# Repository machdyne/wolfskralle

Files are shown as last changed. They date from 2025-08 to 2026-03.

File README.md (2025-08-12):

# Wolfskralle Programmer

Wolfskralle is an ISP + spring contact programmer for CH32 MCUs and [Zwölf](https://github.com/machdyne/zwolf) [LS10](https://machdyne.com/product/zwolf-ls10/) modules.

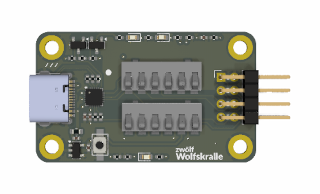
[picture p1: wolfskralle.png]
Wolfskralle


This repo will contain schematics, pinouts and a 3D-printable socket housing for the spring connector.

Find more information on the [Wolfskralle product page](https://machdyne.com/product/wolfskralle-programmer/).

## Pinout

```
7 5 3 1
8 6 4 2
```

| Pin | Signal |
| --- | --- |
| 1 | ZP1 (Zwölf GSCL) / SWCLK | 
| 3 | ZP2 (Zwölf GSDA) | 
| 5 | SWIO (programmer swio) | 
| 7 | RESET (programmer reset) | 
| 2 | TPWR3V3 (target power) | 
| 4 | TSWIO (target swio) | 
| 6 | TRESET (target reset) | 
| 8 | GND | 

## License

The contents of this repo are released under the [Lone Dynamics Open License](LICENSE.md).

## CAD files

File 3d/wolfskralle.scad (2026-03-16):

/*
 * Wolfskralle Socket Housing
 * Copyright (c) 2025 Lone Dynamics Corporation. All rights reserved.
 *
 * required hardware:
 *  - 4 x M3 x 16mm countersunk bolts
 *  - 4 x M3 nuts
 *
 */

$fn = 100;

height = 16 - 1.6 - 2;

mmx();

module mmx() {    
        
    translate([5,0,0]) cube([2,10,height], center=true);    
    
    difference() {
        
        union() {
        translate([-21,0,3.7]) cube([15,28,5], center=true);    
        cube([28,28,height], center=true);    
        }
        
        translate([10,0,-12.5+5.5]) cube([10,25/2,height], center=true);    
        
        translate([-4,0,0]) cube([10,25,15], center=true);    
        
        translate([0,0,-5]) cube([25,10,5], center=true);    
        
        translate([-5,16,-8]) cube([23,15,5], center=true);    
        translate([-5,-16,-8]) cube([23,15,5], center=true);    

        translate([-4.25,-0.5,3]) cube([16.5,14,20], center=true);
        
        //translate([-3,0,-10]) cube([19,19,20], center=true);

        translate([21/2, 12.5-3, -10]) cylinder(d=3.2, h=100);
        translate([21/2, -12.5+3, -10]) cylinder(d=3.2, h=100);
        
        translate([21/2-36, 12.5-3, -10]) cylinder(d=3.2, h=100);
        translate([21/2-36, -12.5+3, -10]) cylinder(d=3.2, h=100);
        
        cylinder(d=3.5, h=100);
        
    }
    
}

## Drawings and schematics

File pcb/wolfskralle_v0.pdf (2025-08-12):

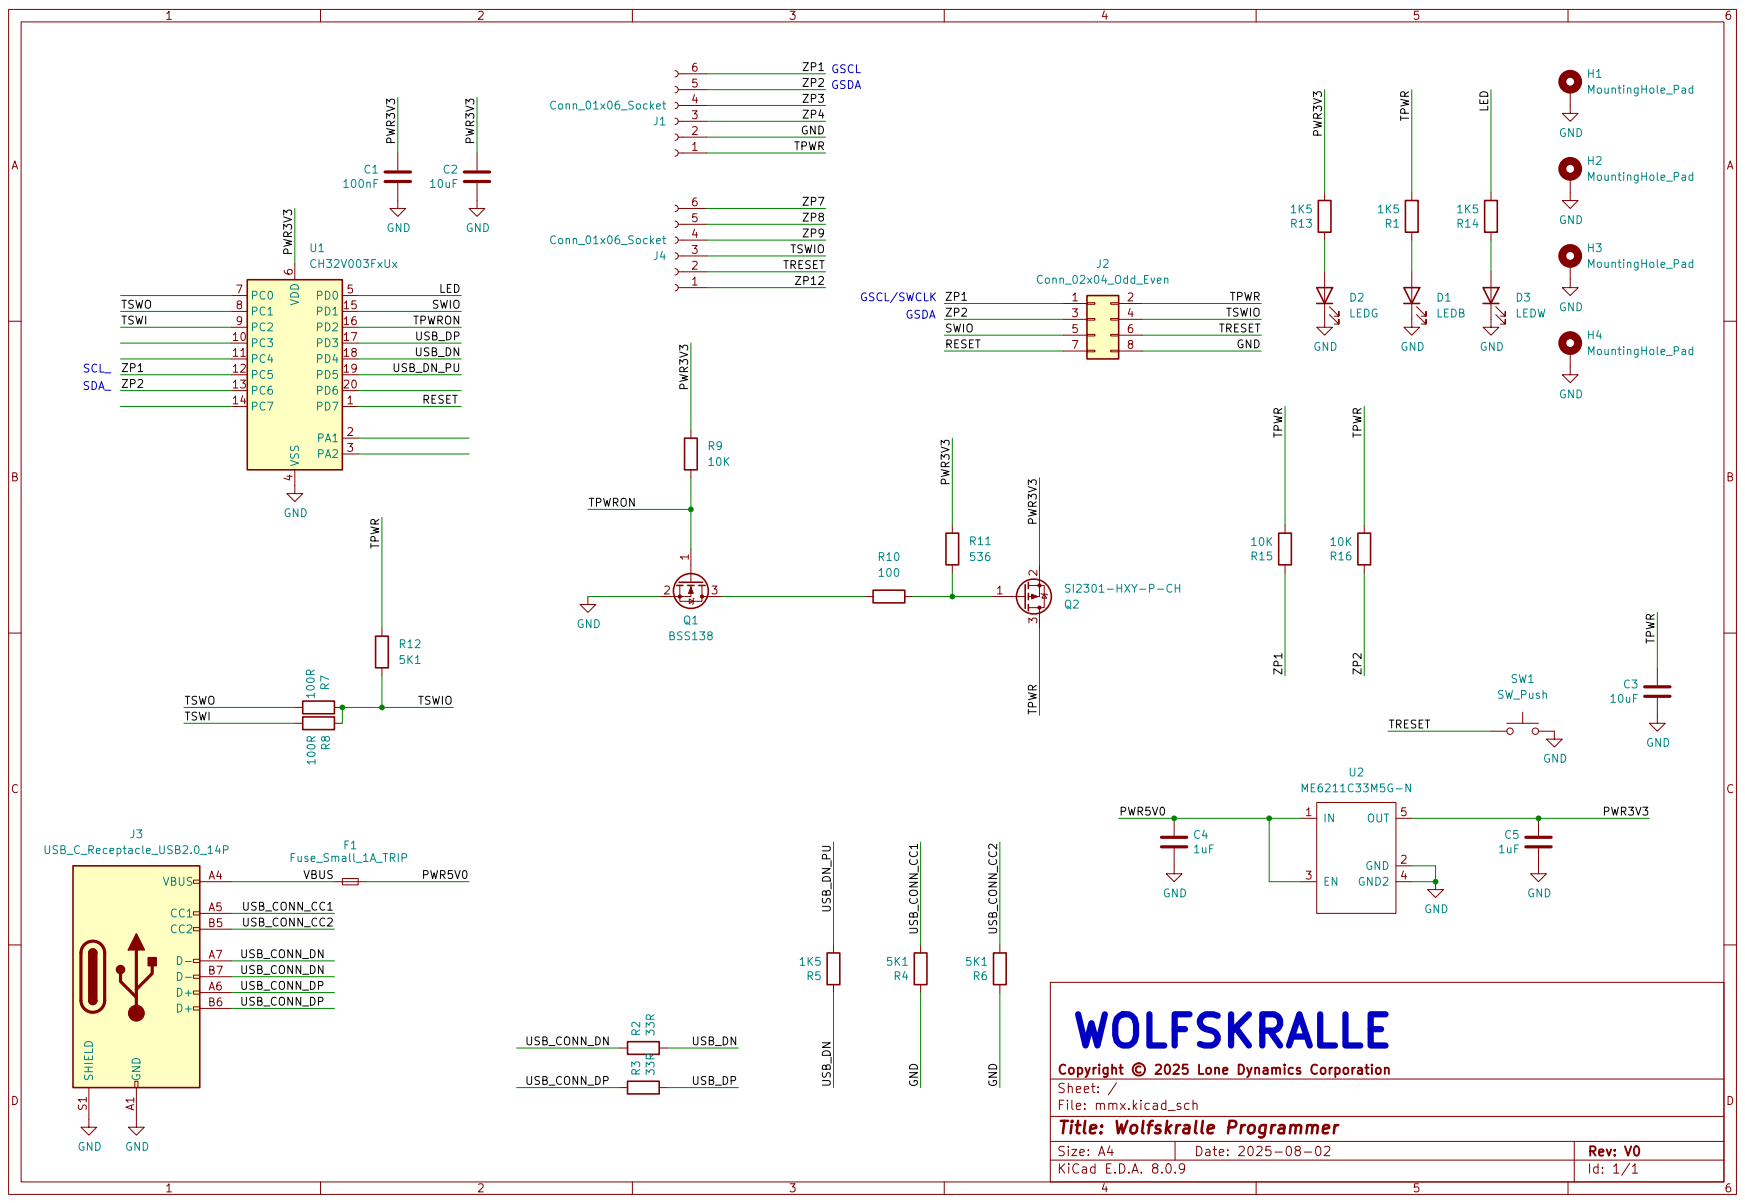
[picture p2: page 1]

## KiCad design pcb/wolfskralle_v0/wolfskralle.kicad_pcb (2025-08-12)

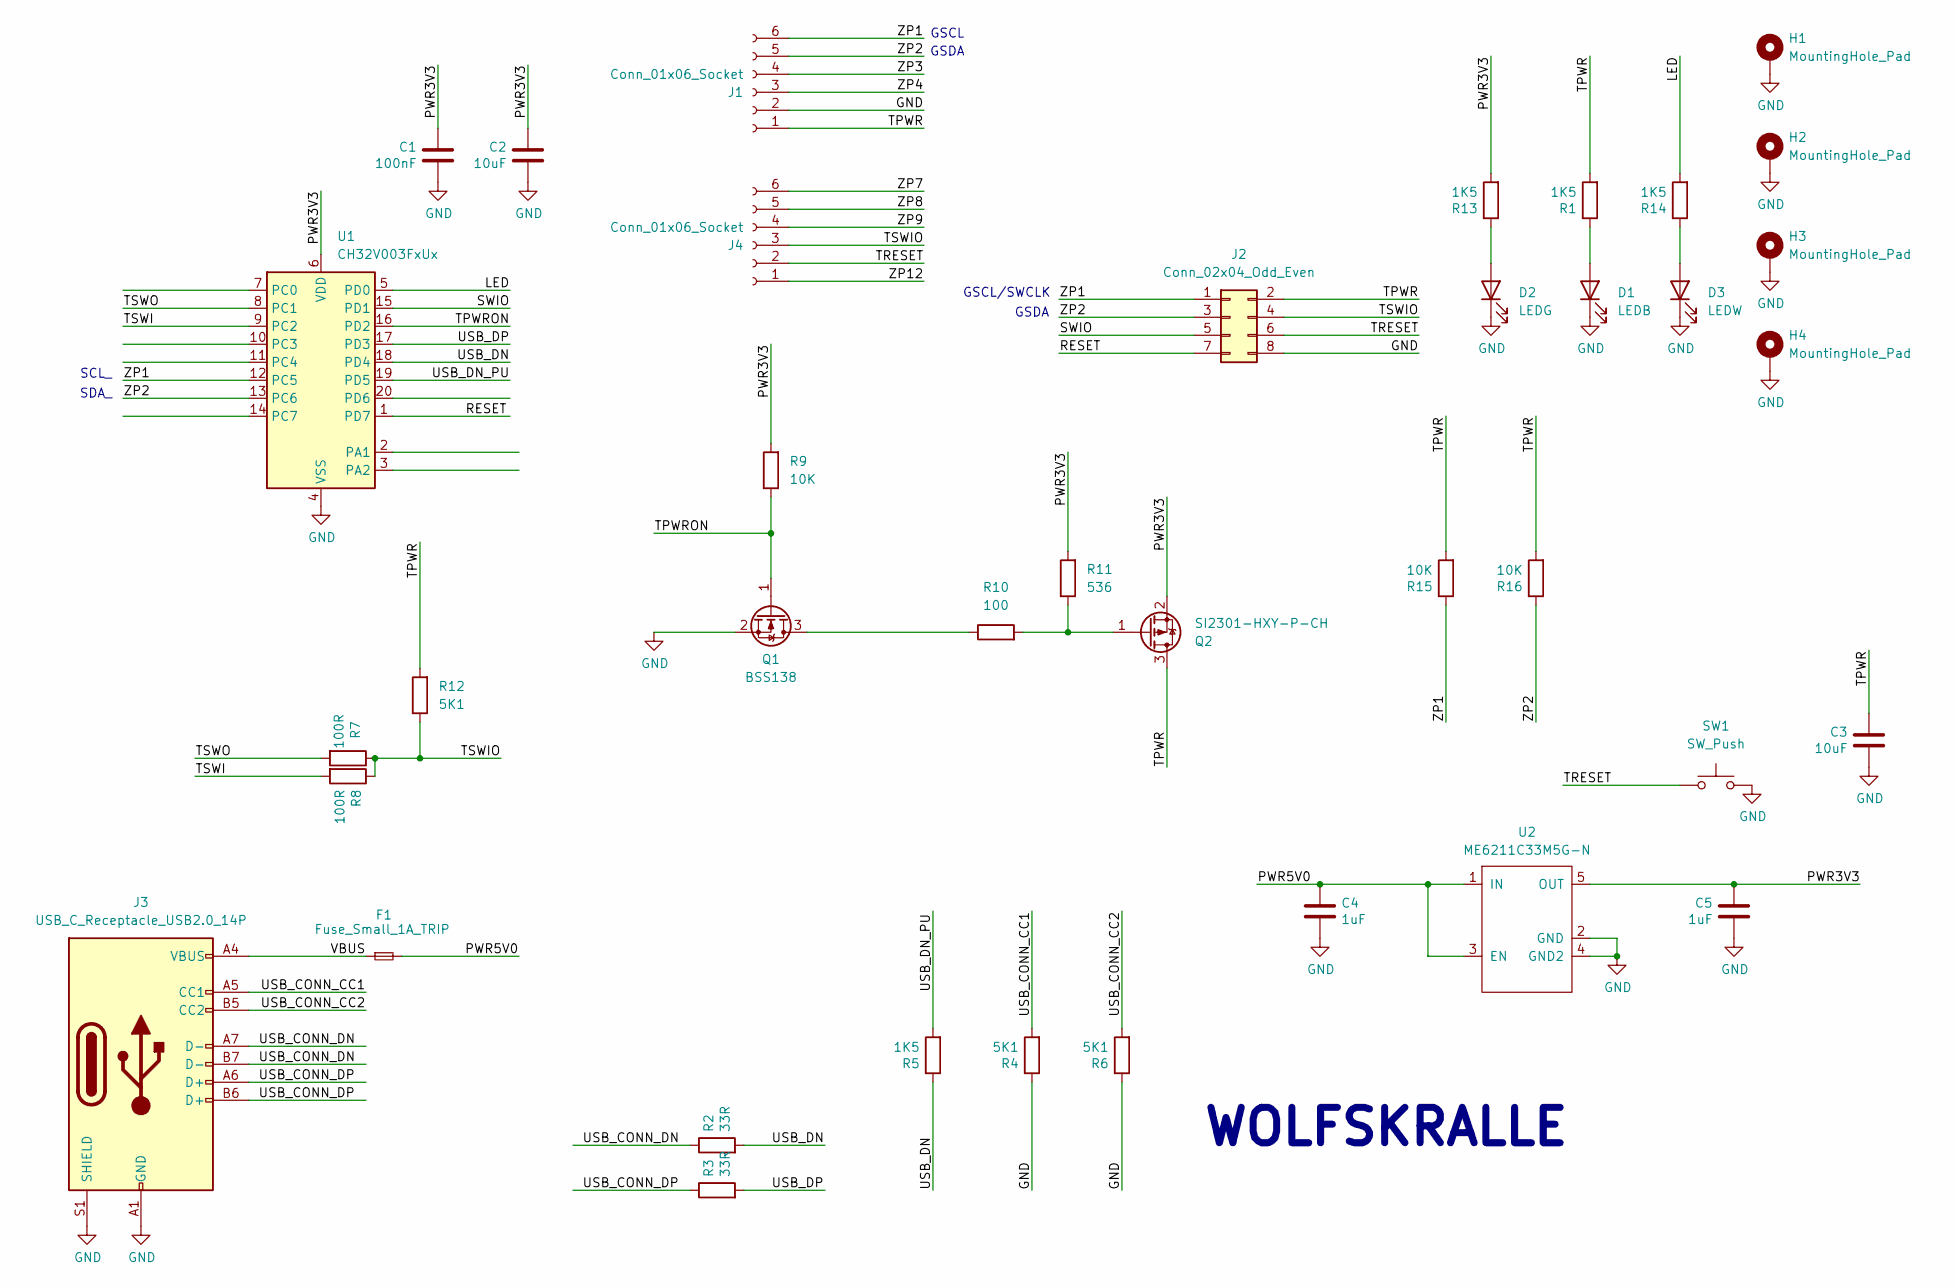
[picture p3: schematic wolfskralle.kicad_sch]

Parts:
C1: 100nF; C_0402_1005Metric
C2, C3: 10uF; C_0402_1005Metric
C4, C5: 1uF; C_0402_1005Metric
D1: LEDB; LED_0603_1608Metric
D2: LEDG; LED_0603_1608Metric
D3: LEDW; LED_0603_1608Metric
F1: Fuse_Small_1A_TRIP; Fuse_0603_1608Metric
H1, H2, H3, H4: MountingHole_Pad; MountingHole_2.7mm_M2.5_DIN965_Pad
J1, J4: Conn_01x06_Socket; SPRING-MALE-6P-TIGHTHOLES
J2: Conn_02x04_Odd_Even; PinHeader_2x04_P2.54mm_Horizontal
J3: USB_C_Receptacle_USB2.0_14P; USB_C_Receptacle_HRO_TYPE-C-31-M-12-BIG-PADS-PASTE
Q1: BSS138; SOT-23
Q2: SI2301-HXY-P-CH; SOT-23
R1, R5, R13, R14: 1K5; R_0402_1005Metric
R2, R3: 33R; R_0402_1005Metric
R4, R6, R12: 5K1; R_0402_1005Metric
R7, R8: 100R; R_0402_1005Metric
R9, R15, R16: 10K; R_0402_1005Metric
R10: 100; R_0402_1005Metric
R11: 536; R_0402_1005Metric
SW1: SW_Push; Button_2P_3x4mm
U1: CH32V003FxUx; QFN-20-1EP_3x3mm_P0.4mm_EP1.65x1.65mm
U2: ME6211C33M5G-N; TSOP-5_1.65x3.05mm_P0.95mm

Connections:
/LED: R14.2, U1.5 (PD0)
/PWR3V3: C1.1, C2.1, C5.1, Q2.2 (S), R9.2, R11.2, R13.2, U1.6 (VDD), U2.5 (OUT)
/PWR5V0: C4.1, F1.2, U2.1 (IN), U2.3 (EN)
/RESET: J2.7, U1.1 (PD7)
/SWIO: J2.5, U1.15 (PD1)
/TPWR: C3.1, J1.1, J2.2, Q2.3 (D), R1.2, R12.2, R15.2, R16.2
/TPWRON: Q1.1 (G), R9.1, U1.16 (PD2)
/TRESET: J2.6, J4.2, SW1.1
/TSWI: R8.2, U1.9 (PC2)
/TSWIO: J2.4, J4.3, R7.1, R8.1, R12.1
/TSWO: R7.2, U1.8 (PC1)
/USB_CONN_CC1: J3.A5 (CC1), R4.2
/USB_CONN_CC2: J3.B5 (CC2), R6.2
/USB_CONN_DN: J3.A7 (D-), J3.B7 (D-), R2.1
/USB_CONN_DP: J3.A6 (D+), J3.B6 (D+), R3.1
/USB_DN: R2.2, R5.1, U1.18 (PD4)
/USB_DN_PU: R5.2, U1.19 (PD5)
/USB_DP: R3.2, U1.17 (PD3)
/VBUS: F1.1, J3.A4 (VBUS), J3.A9 (VBUS), J3.B4 (VBUS), J3.B9 (VBUS)
/ZP1: J1.6, J2.1, R15.1, U1.12 (PC5)
/ZP2: J1.5, J2.3, R16.1, U1.13 (PC6)
/ZP3: J1.4
/ZP4: J1.3
/ZP7: J4.6
/ZP8: J4.5
/ZP9: J4.4
/ZP12: J4.1
GND: C1.2, C2.2, C3.2, C4.2, C5.2, D1.1 (K), D2.1 (K), D3.1 (K), H1.1, H2.1, H3.1, H4.1, J1.2, J2.8, J3.A1 (GND), J3.A12 (GND), J3.B1 (GND), J3.B12 (GND), J3.S1 (SHIELD), Q1.2 (S), R4.1, R6.1, SW1.2, U1.4 (VSS), U1.21 (VSS), U2.2 (GND), U2.4 (GND2)
unnamed: D1.2 (A), R1.1
unnamed: D2.2 (A), R13.1
unnamed: D3.2 (A), R14.1
unnamed: Q1.3 (D), R10.1
unnamed: Q2.1 (G), R10.2, R11.1

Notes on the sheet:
GSCL
GSDA
SCL_
GSCL/SWCLK
WOLFSKRALLE
SDA_

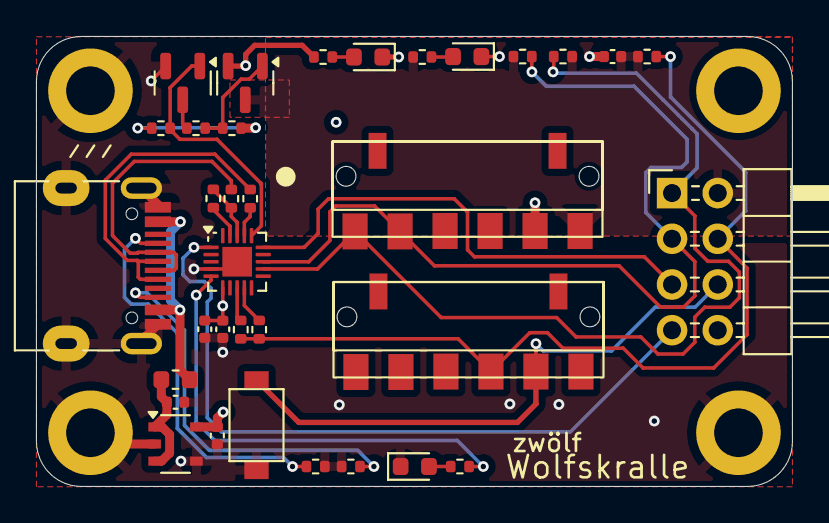
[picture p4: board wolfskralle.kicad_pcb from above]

Board: 2 copper layers, 42.0 x 25.0 mm, 38 parts (0 on the bottom side), 27 nets.

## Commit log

2026-03-16 add 3d components
    [wolfskralle.scad]
2026-03-16 update hardware notes
    [wolfskralle.scad]
